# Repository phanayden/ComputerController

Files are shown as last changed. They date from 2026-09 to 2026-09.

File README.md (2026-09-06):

# ComputerController
Custom Computer Controller that uses a custom PCB to control the media functions of the device it is connected to, as well as view the loudness of the room. 

## Key Project Features
* MODE switching button that changes the use of the rotary encoder between VOLUME, MIC GAIN, BRIGHTNESS, and MIC SENSITIVITY
* PLAY, NEXT, BACK, MUTE MIC buttons
* LCD Screen that shows the current volume, mic loudness and gain, mode, if the volume is muted, if the mic is muted, and when each button is pressed
* Each component has a coupling and bulk capacitor
* LED Ring that displays the current volume level in green, and turns red when muted

## Components
* **Microcontroller:** ESP32-S3 N16R8 Development Board
* **Display:** Hosyond 3.5 Inches TFT LCD Touch Screen Shield Display Module 480x320 SPI Serial ILI9488
* **Microphone:** Teyleten Robot MAX9814 Electret Microphone
* **Rotary Encoder:** EC11 Rotary Encoder with Push Button
* **Switches:** GATERON Creamy Keyboard Switches
* **LED Ring:** WS2812B RGB LED Rings 12 Bits

## Hardware Architecture and Visuals
### Circuit Schematic
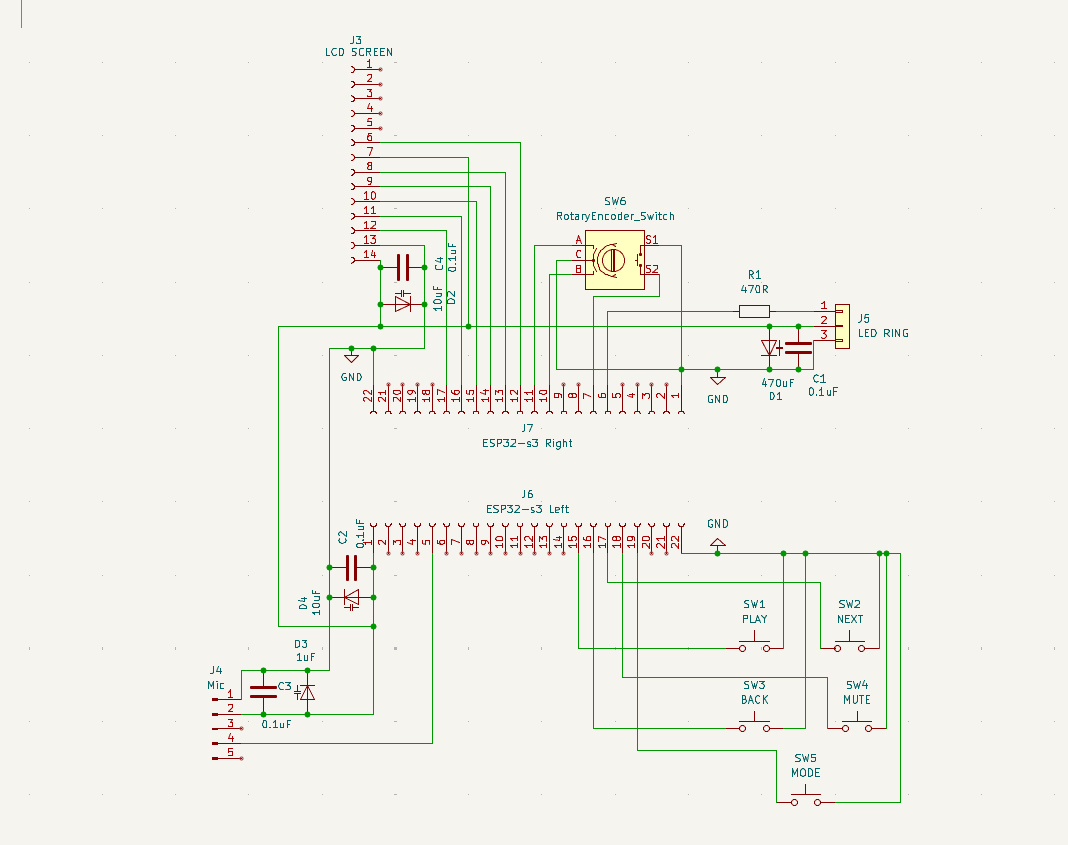
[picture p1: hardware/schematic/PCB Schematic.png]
Circuit Schematic

### Circuit Design
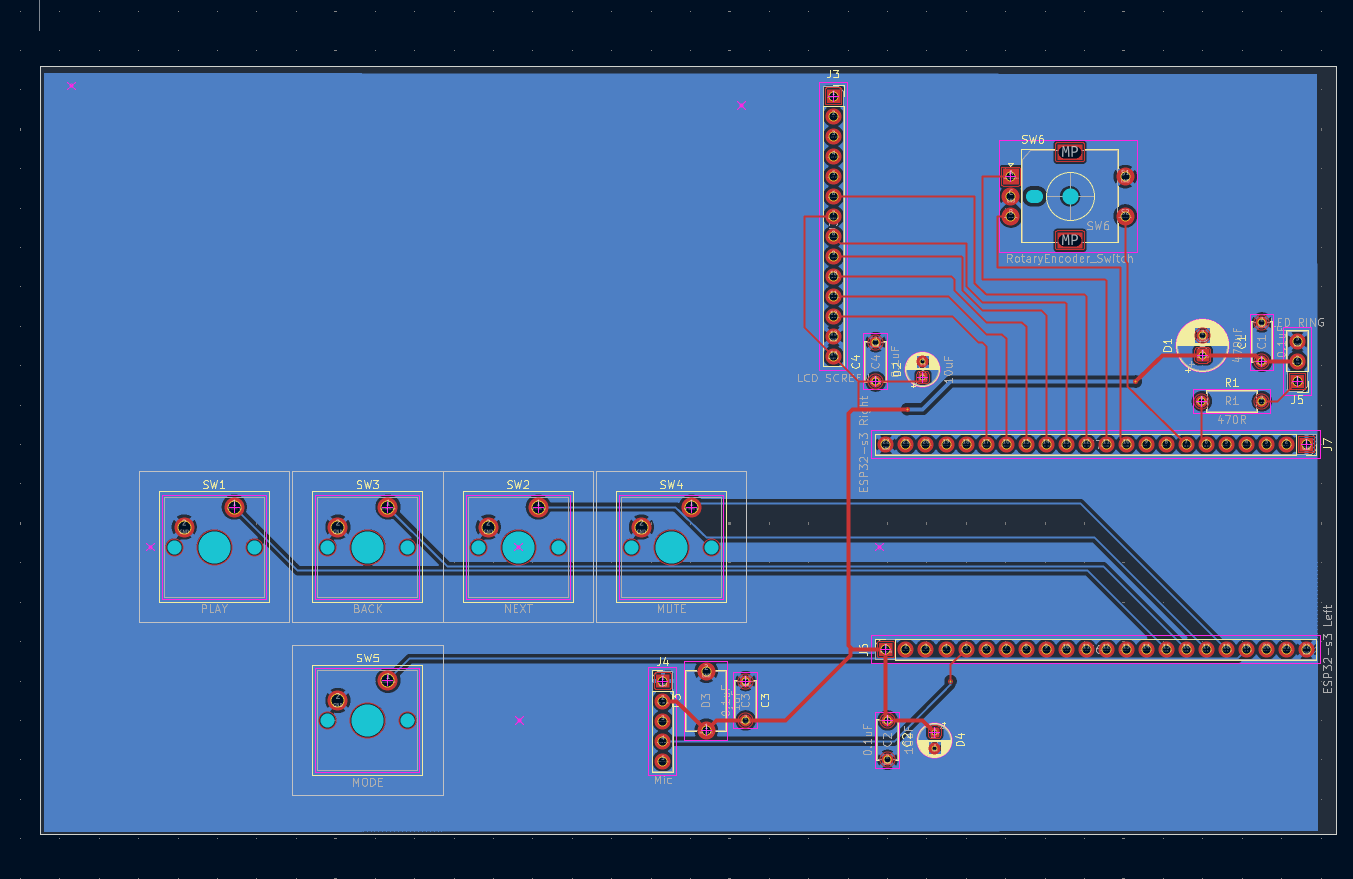
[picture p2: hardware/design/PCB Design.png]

### 3D PCB Layout
TOP
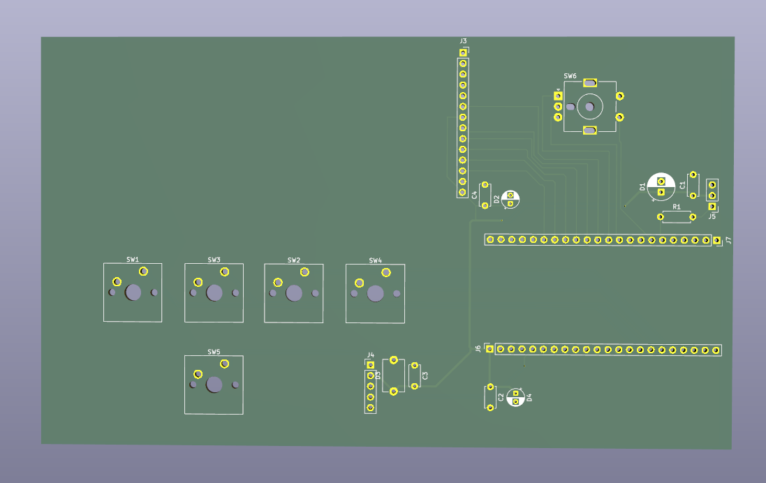
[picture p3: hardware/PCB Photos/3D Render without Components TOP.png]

BOTTOM
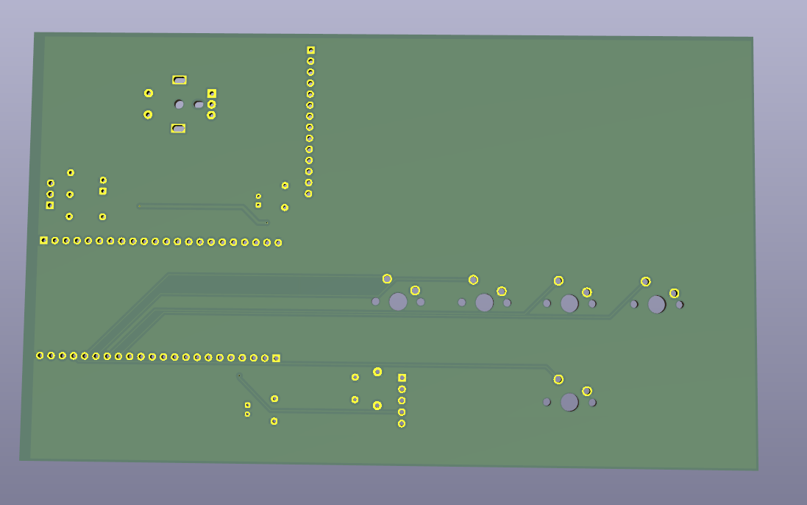
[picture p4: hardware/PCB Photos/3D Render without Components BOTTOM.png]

### Physical PCB

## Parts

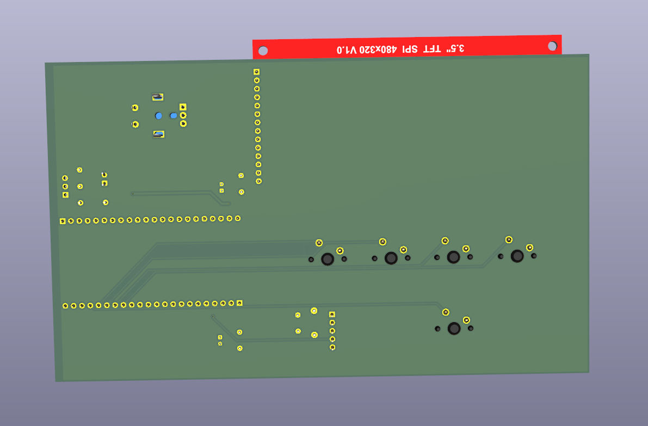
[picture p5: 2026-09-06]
hardware/PCB Photos/3D Render with Components BOTTOM.png

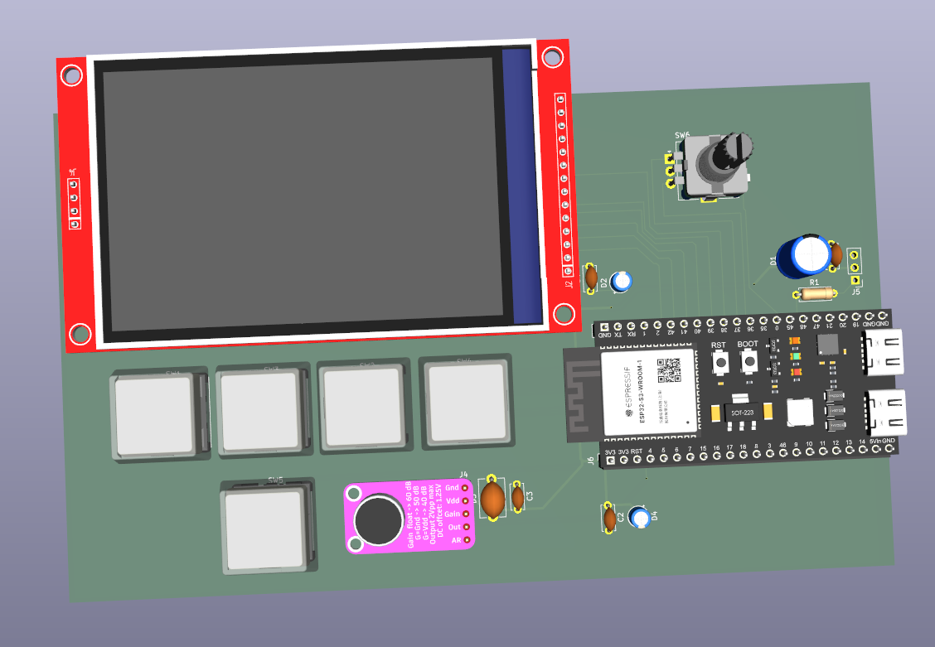
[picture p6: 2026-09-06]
hardware/PCB Photos/3D Render with Components TOP.png

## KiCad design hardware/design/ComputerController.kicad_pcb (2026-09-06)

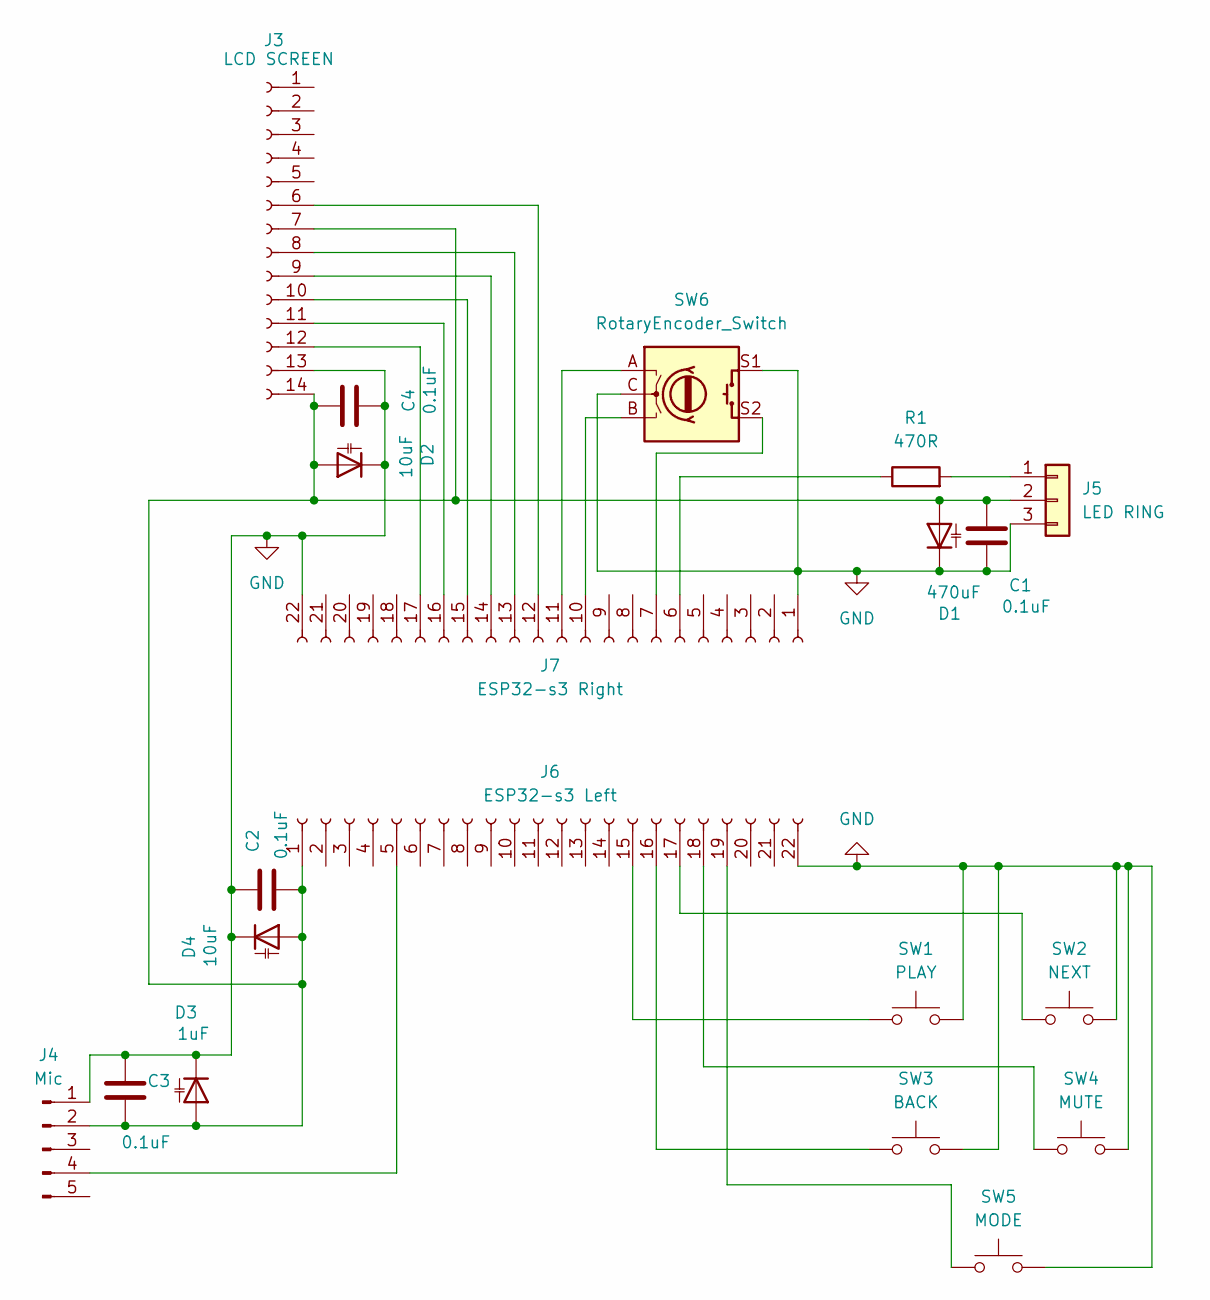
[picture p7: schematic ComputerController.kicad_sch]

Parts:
C1, C2, C3, C4: 0.1uF; C_Disc_D5.0mm_W2.5mm_P5.00mm
D1: 470uF; CP_Radial_D6.3mm_P2.50mm
D2, D4: 10uF; CP_Radial_D4.0mm_P2.00mm
D3: 1uF; C_Disc_D7.5mm_W5.0mm_P7.50mm
J3: LCD SCREEN; PinSocket_1x14_P2.54mm_Vertical
J4: Mic; PinHeader_1x05_P2.54mm_Vertical
J5: LED RING; PinHeader_1x03_P2.54mm_Vertical
J6: ESP32-s3 Left; PinSocket_1x22_P2.54mm_Vertical
J7: ESP32-s3 Right; PinSocket_1x22_P2.54mm_Vertical
R1: 470R; R_Axial_DIN0207_L6.3mm_D2.5mm_P7.62mm_Horizontal
SW1: PLAY; SW_Cherry_MX_1.00u_PCB
SW2: NEXT; SW_Cherry_MX_1.00u_PCB
SW3: BACK; SW_Cherry_MX_1.00u_PCB
SW4: MUTE; SW_Cherry_MX_1.00u_PCB
SW5: MODE; SW_Cherry_MX_1.00u_PCB
SW6: RotaryEncoder_Switch; RotaryEncoder_Alps_EC11E-Switch_Vertical_H20mm_MountingHoles

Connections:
GND: C1.2, C2.2, C3.1, C4.2, D1.2 (K), D2.2 (K), D3.2 (K), D4.2 (K), J3.13, J4.1, J5.3, J6.22, J7.1, J7.22, SW1.2, SW2.2, SW3.2, SW4.2, SW5.2, SW6.C, SW6.S1
unnamed: C1.1, C2.1, C3.2, C4.1, D1.1 (A), D2.1 (A), D3.1 (A), D4.1 (A), J3.7, J3.14, J4.2, J5.2, J6.1
unnamed: J3.6, J7.12
unnamed: J3.8, J7.13
unnamed: J3.9, J7.14
unnamed: J3.10, J7.15
unnamed: J3.11, J7.16
unnamed: J3.12, J7.17
unnamed: J4.4, J6.5
unnamed: J5.1, R1.2
unnamed: J6.15, SW1.1
unnamed: J6.16, SW3.1
unnamed: J6.17, SW2.1
unnamed: J6.18, SW4.1
unnamed: J6.19, SW5.1
unnamed: J7.6, R1.1
unnamed: J7.7, SW6.S2
unnamed: J7.10, SW6.B
unnamed: J7.11, SW6.A

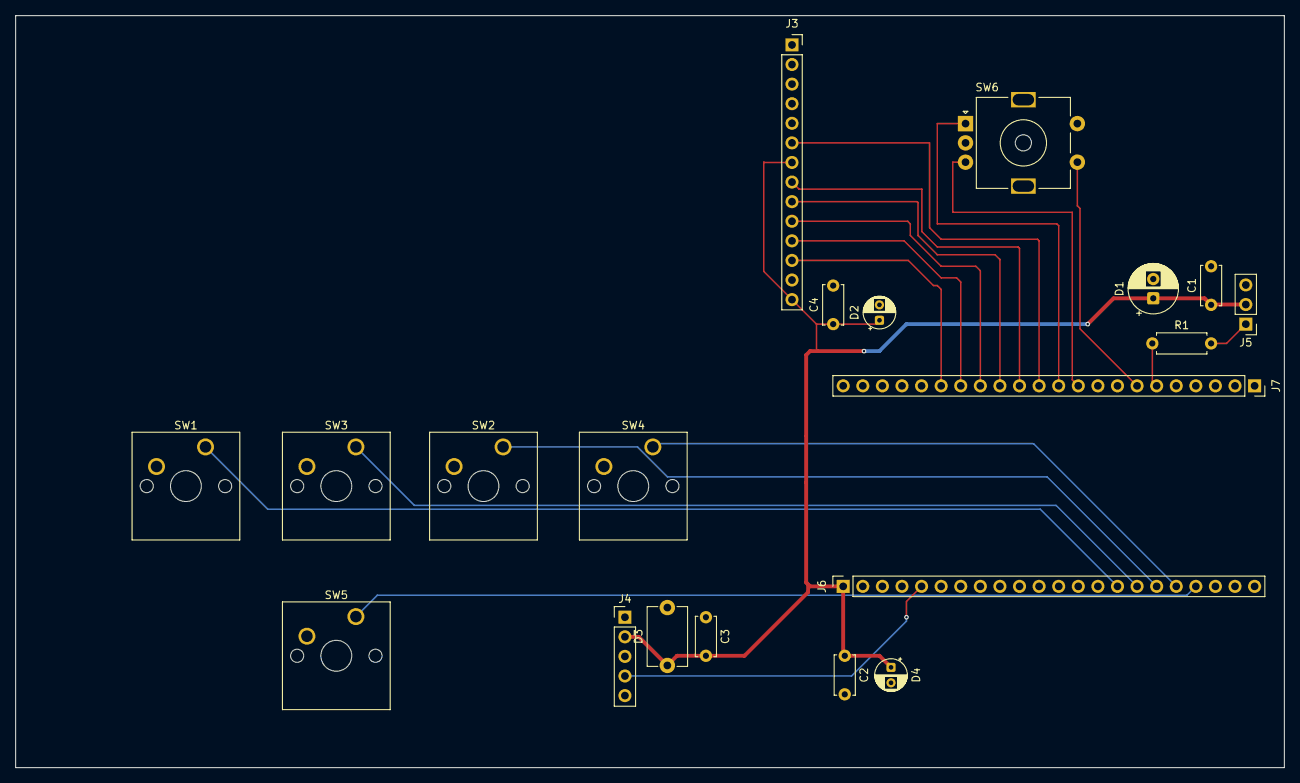
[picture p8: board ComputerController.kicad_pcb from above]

Board: 2 copper layers, 164.5 x 97.5 mm, 20 parts (0 on the bottom side), 19 nets.

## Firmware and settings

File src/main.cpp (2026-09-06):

#include <Arduino.h>
#include <FastLED.h>
#include "config.h"
#include "io/led_ring.h"
#include "io/encoder.h"
#include "io/mic.h"
#include "io/buttons.h"
#include "io/screen.h"
#include "io/hid_controls.h"

int volume = 0;
bool muted = false;
bool micMuted = false;

unsigned long lastMicUpdateTime = 0;

EncoderState encoder;

int micSensitivity = 100; // 100% = normal sensitivity

enum ControllerMode {
  MODE_VOLUME,
  MODE_MIC_GAIN,
  MODE_LIGHTING,
  MODE_WAVEFORM
};

int ledBrightness = LED_BRIGHTNESS;

CRGB ledColors[] = {
    CRGB::Green,
    CRGB::Blue,
    CRGB::Purple,
    CRGB::Cyan,
    CRGB::White,
    CRGB::Yellow
};

int currentLedColorIndex = 0;
const int NUM_LED_COLORS = sizeof(ledColors) / sizeof(ledColors[0]);

ControllerMode currentMode = MODE_VOLUME;

const int NUM_MODES = 4;

int waveformScale = 100;       // 100% = normal waveform height
bool waveformFrozen = false;

//used to apply the read volume to the controller on startup
void applyComputerVolume(int newVolume) {
  volume = constrain(newVolume, 0, 100);

  if (muted) {
    mutedLED(true, volume);
  } else {
    setLedRingVolume(volume);
  }

  updateVolumeUI(volume);
}

//reads the command and looks for the number after VOL:, and sets the correct read volume level when first booting
//also reads if sound is muted or not
void handleHostCommand(const String &command) {
  if (command.startsWith("VOL:")) {
    applyComputerVolume(command.substring(4).toInt());
    Serial.print("VOL_OK:");
    Serial.println(volume);
    return;
  }

  if (command.startsWith("MUTE:")) {
    muted = command.substring(5).toInt() != 0;
    mutedLED(muted, volume);
    updateMutedUI(muted);
    Serial.print("MUTE_OK:");
    Serial.println(muted ? 1 : 0);
    return;
  }
}

//goes first, reads the charactesr sent from macos.py, and sends the sentence/command to handleHostCommand
void updateHostSerial() {
  static String command;

  while (Serial.available() > 0) {
    char c = (char)Serial.read();

    if (c == '\n' || c == '\r') {
      if (command.length() > 0) {
        handleHostCommand(command);
        command = "";
      }
      continue;
    }

    if (command.length() < 32) {
      command += c;
    } else {
      command = "";
    }
  }
}

void setup() {
  Serial.begin(115200);
  delay(1000);
  Serial.println("BOOT: setup started");

  Serial.println("BOOT: HID init");
  initHidControls();
  Serial.println("BOOT: LED ring init");
  Serial.flush();
  initLedRing();
  Serial.println("BOOT: encoder init");
  Serial.flush();
  initEncoder(encoder, ENCODER_A_PIN, ENCODER_B_PIN, ENCODER_SW_PIN);
  Serial.println("BOOT: mic init");
  Serial.flush();
  initMic();
  Serial.println("BOOT: buttons init");
  Serial.flush();
  initButtons();
  Serial.println("BOOT: screen init");
  Serial.flush();
  initScreen();

  Serial.println("BOOT: drawing UI");
  Serial.flush();
  setLedRingVolume(volume);
  updateVolumeUI(volume);
  updateMutedUI(muted);
  updateMicUI(0);
  updateWaveformUI(0);
  updateMicMuteButtonUI(micMuted);
  updateMicGainUI(micSensitivity);
  #if defined(CONFIG_TINYUSB_HID_ENABLED)
    Serial.println("HID enabled");
  #else
    Serial.println("HID NOT enabled - check build flags");
  #endif

  Serial.println("PC_CONTROLLER_READY");
  Serial.flush();
}

void updateMode() {
  if (toggleStatePressed()) {
    currentMode = (ControllerMode)((currentMode + 1) % NUM_MODES);

    updateModeUI((int)currentMode);

    Serial.print("Mode changed to: ");
    Serial.println(currentMode);
  }
}

void handleVolumeMode(int volumeDelta){
  if (volumeDelta != 0 && !muted) {
    volume += volumeDelta * 2;
    volume = constrain(volume, 0, 100);

    if (volumeDelta > 0) {
      sendComputerVolumeUp(volumeDelta * VOLUME_STEP);
    } else {
      sendComputerVolumeDown(-volumeDelta * VOLUME_STEP);
    }

    setLedRingVolume(volume);
    updateVolumeUI(volume);
  }

  if (encoderButtonPressed(encoder)) {
    muted = !muted;

    sendComputerMute();
    mutedLED(muted, volume);
    updateMutedUI(muted);

  }
}

void handleMicGainMode(int encoderDelta){
  if (encoderDelta != 0 && !micMuted) {
    micSensitivity += encoderDelta * MIC_SENSITIVITY_STEP;
    micSensitivity = constrain(micSensitivity, MIC_SENSITIVITY_MIN, MIC_SENSITIVITY_MAX);

    updateMicGainUI(micSensitivity);

    Serial.print("Mic sensitivity: ");
    Serial.print(micSensitivity);
    Serial.println("%");
  }
  if (encoderButtonPressed(encoder)) {
    micMuted = !micMuted;
    updateMicMuteButtonUI(micMuted);
    if (micMuted) {
      updateMicUI(0);
      updateWaveformUI(0);
    }
  }
}

void handleLightingMode(int delta) {
  if (delta != 0) {
    ledBrightness += delta * 5;
    ledBrightness = constrain(ledBrightness, 0, 255);

    setLedRingBrightness(ledBrightness);
    setLedRingColor(ledColors[currentLedColorIndex], volume);

    Serial.print("LED brightness: ");
    Serial.println(ledBrightness);
  }

  if (encoderButtonPressed(encoder)) {
    currentLedColorIndex = (currentLedColorIndex + 1) % NUM_LED_COLORS;

    setLedRingColor(ledColors[currentLedColorIndex], volume);

    Serial.print("LED color index: ");
    Serial.println(currentLedColorIndex);
  }
}

void handleWaveformMode(int delta) {
  if (delta != 0) {
    waveformScale += delta * 10;
    waveformScale = constrain(waveformScale, 50, 200);

    Serial.print("Waveform scale: ");
    Serial.print(waveformScale);
    Serial.println("%");
  }

  if (encoderButtonPressed(encoder)) {
    waveformFrozen = !waveformFrozen;

    Serial.print("Waveform frozen: ");
    Serial.println(waveformFrozen);
  }
}

void loop() {
  //updateHostSerial();
  updateEncoder(encoder);
  updateButtons();
  updateMode();
  int encoderDelta = getEncoderDelta(encoder); 

  switch (currentMode) {
    case MODE_VOLUME:
      handleVolumeMode(encoderDelta);
      break;

    case MODE_MIC_GAIN:
      handleMicGainMode(encoderDelta);
      break;

    case MODE_LIGHTING:
      handleLightingMode(encoderDelta);
      break;

    case MODE_WAVEFORM:
      handleWaveformMode(encoderDelta);
      break;
  }

  unsigned long now = millis();

  if (now - lastMicUpdateTime >= MIC_UPDATE_INTERVAL_MS) {
    lastMicUpdateTime = now;

    int micLoudness = getMicLoudnessPercent();

    int adjustedLoudness = micLoudness * micSensitivity / 100;
    adjustedLoudness = constrain(adjustedLoudness, 0, 100);

    static float smoothLoudness = 0;
    smoothLoudness = 0.85 * smoothLoudness + 0.15 * adjustedLoudness;

    if (smoothLoudness < 8) {
    smoothLoudness = 0;
    }

    int displayLoudness = (int)smoothLoudness;

    int scaledWaveformLoudness = displayLoudness * waveformScale / 100;
    scaledWaveformLoudness = constrain(scaledWaveformLoudness, 0, 100);

    if (!micMuted) {
      updateMicUI(displayLoudness);

      if (!waveformFrozen) {
        updateWaveformUI(scaledWaveformLoudness);
      }
    } else {
      updateMicUI(0);

      if (!waveformFrozen) {
        updateWaveformUI(0);
      }
    }
  }

  if (playPausePressed()) {
    sendComputerPlayPause();
    updatePlayPauseButtonUI(true);
    delay(80);
    updatePlayPauseButtonUI(false);
  }

  if (skipBackPressed()) {
    sendComputerPrevious();
    updateSkipBackButtonUI(true);
    delay(80);
    updateSkipBackButtonUI(false);
  }

  if (skipNextPressed()) {
    sendComputerNext();
    updateSkipNextButtonUI(true);
    delay(80);
    updateSkipNextButtonUI(false);
  }

  if (micMutePressed()) {
    micMuted = !micMuted;

    updateMicMuteButtonUI(micMuted);

    if (micMuted) {
      updateMicUI(0);
      updateWaveformUI(0);
    }
  }
}

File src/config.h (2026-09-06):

#pragma once

// =====================
// LED Ring
// =====================
#define LED_RING_PIN 42
#define NUM_LEDS 12
#define LED_BRIGHTNESS 20


// =====================
// Microphone
// =====================
#define MIC_PIN 5


// =====================
// Encoder
// =====================
#define ENCODER_A_PIN 36
#define ENCODER_B_PIN 35
#define ENCODER_SW_PIN 45


// =====================
// Push Buttons
// =====================
#define PLAY_PAUSE_BUTTON_PIN 9
#define SKIP_BACK_BUTTON_PIN  10
#define SKIP_NEXT_BUTTON_PIN  11
#define MIC_MUTE_BUTTON_PIN   12
#define MODE_BUTTON_PIN       13



// =====================
// App Settings
// =====================
#define VOLUME_STEP 1

#define MIC_SENSITIVITY_MIN 25
#define MIC_SENSITIVITY_MAX 200
#define MIC_SENSITIVITY_STEP 5

#define MIC_UPDATE_INTERVAL_MS 200

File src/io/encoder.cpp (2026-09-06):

#include "encoder.h"
#include "../config.h"

#include <Arduino.h>

static const unsigned long DEBOUNCE_MS = 50;

void initEncoder(EncoderState &encoder, int pinA, int pinB, int pinSW) {
  // Save pin numbers into this specific encoder object
  encoder.pinA = pinA;
  encoder.pinB = pinB;
  encoder.pinSW = pinSW;

  pinMode(encoder.pinA, INPUT_PULLUP);
  pinMode(encoder.pinB, INPUT_PULLUP);
  pinMode(encoder.pinSW, INPUT_PULLUP);

  int a = digitalRead(encoder.pinA);
  int b = digitalRead(encoder.pinB);

  encoder.lastEncoded = (a << 1) | b;
  encoder.encoderAccumulator = 0;
  encoder.delta = 0;

  encoder.lastButtonReading = digitalRead(encoder.pinSW);
  encoder.stableButtonState = encoder.lastButtonReading;
  encoder.buttonPressedEvent = false;
  encoder.lastDebounceTime = 0;
}

// Updates one encoder.
// Valid quadrature sequence changes one bit at a time.
void updateEncoder(EncoderState &encoder) {
  int a = digitalRead(encoder.pinA);
  int b = digitalRead(encoder.pinB);

  uint8_t encoded = (a << 1) | b;
  uint8_t transition = (encoder.lastEncoded << 2) | encoded;

  // Valid quadrature transitions for one direction
  if (transition == 0b1101 ||
      transition == 0b0100 ||
      transition == 0b0010 ||
      transition == 0b1011) {
    encoder.encoderAccumulator++;
  }

  // Valid quadrature transitions for the other direction
  if (transition == 0b1110 ||
      transition == 0b0111 ||
      transition == 0b0001 ||
      transition == 0b1000) {
    encoder.encoderAccumulator--;
  }

  encoder.lastEncoded = encoded;

  // Most EC11 encoders produce about 4 transitions per physical click.
  if (encoder.encoderAccumulator >= 4) {
    encoder.delta++;
    encoder.encoderAccumulator = 0;
  }

  if (encoder.encoderAccumulator <= -4) {
    encoder.delta--;
    encoder.encoderAccumulator = 0;
  }

  // Button debounce
  bool reading = digitalRead(encoder.pinSW);

  if (reading != encoder.lastButtonReading) {
    encoder.lastDebounceTime = millis();
  }

  if ((millis() - encoder.lastDebounceTime) > DEBOUNCE_MS) {
    if (reading != encoder.stableButtonState) {
      encoder.stableButtonState = reading;

      // INPUT_PULLUP means pressed = LOW
      if (encoder.stableButtonState == LOW) {
        encoder.buttonPressedEvent = true;
      }
    }
  }

  encoder.lastButtonReading = reading;
}

int getEncoderDelta(EncoderState &encoder) {
  int delta = encoder.delta;
  encoder.delta = 0;
  return delta;
}

bool encoderButtonPressed(EncoderState &encoder) {
  if (encoder.buttonPressedEvent) {
    encoder.buttonPressedEvent = false;
    return true;
  }

  return false;
}
